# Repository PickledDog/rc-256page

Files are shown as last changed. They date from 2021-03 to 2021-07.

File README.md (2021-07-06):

# rc-256page
 128K+128K fully pageable RAM/ROM card for RC2014
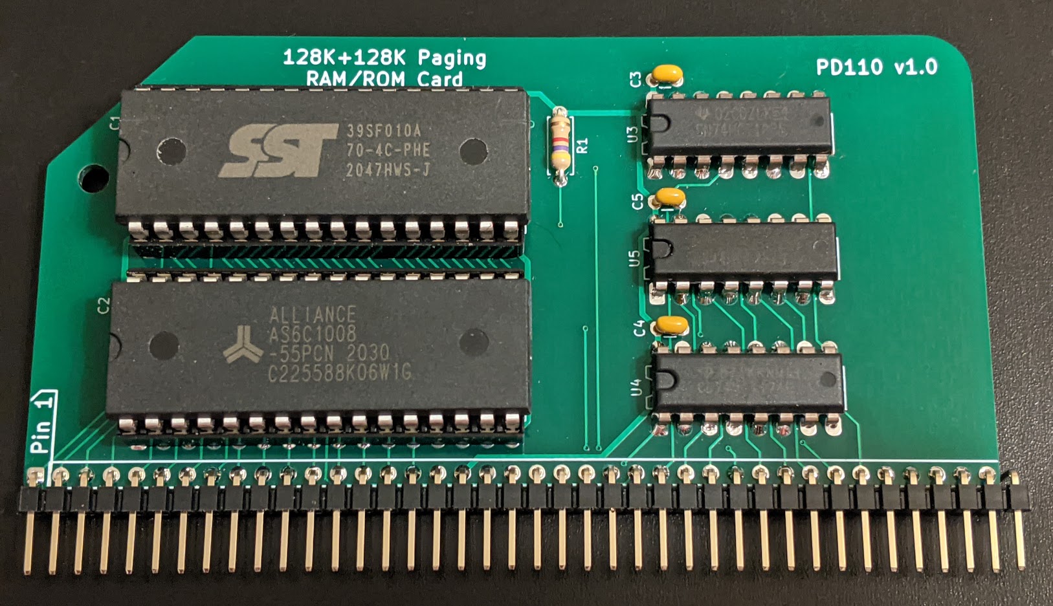
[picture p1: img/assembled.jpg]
Assembled PD110


## Overview
This RC2014-compatible board provides RAM and flash ROM, software-pageable in 32k pages. 4 ROM and 4 RAM pages may be paged into both the lower and upper 32k of Z80 memory.

## Memory details
For ROM, a SST39SF010 128k x 8 flash chip is used. It can be programmed in-place using Will Sowerbutts' FLASH4 utility (included with RomWBW). For RAM, an AS6C1008 128k x 8 SRAM is used, providing 128K of addressable memory. Both are divided into 32k pages, and are presented to the system via 2 32k address blocks (so 2 pages selectable from 8 total).

## Paging
Upon reset, ROM page 0 is mapped to both the lower **and** upper 32k (initialization code in page 0 *must* select a RAM page for normal operation). A single config register is used to set **both** currently mapped pages, presented as an I/O device at 0x78 (the address used by most "large" Z80 memory systems). The low nibble of this configures the lower page, and the high nibble the higher page. For each nibble, the high bit selects the chip (0 for ROM, 1 for RAM).

## Firmware
This board can be used as an affordable way to add [RomWBW](https://github.com/wwarthen/RomWBW) support to an RC2014 (see below). It is also presented as a programming challenge for adventurous RC2014 builders, who want an inexpensive way to add fully software-pageable memory to their computers. Beyond RomWBW, *there are currently no standard ROM images for this board* (that is, no BASIC ROM etc). None of the standard RC2014 ROM images can be used as-is. Building a ROM image (or modifying an existing one) is left up to the user.

### RomWBW
For RomWBW, a new memory mapper needs to be added. A patch file to do this can be found in the [firmware](/firmware) directory (along with an example image).

## Part selection
Bill Of Materials and part references are below. I recommend using gold-plated header for the bus connection - I use these ones from [Pololu](https://www.pololu.com/product/967) or [Sparkfun](https://www.sparkfun.com/products/553). A nice detail of these, is that they sit at the same height as double-row header in a backplane.

The specified parts are just the ones I used, and can be substituted as needed - Mouser links provided for convenience and reference.

| Reference | Value | Qty | Mouser link |
| --- | ----- | --- | --- |
| C1-C5 | 100nF ceramic | 5 | [KEMET C315C104M5U5TA](https://www.mouser.com/ProductDetail/C315C104M5U5TA7303) |
| J1 | 1x40 right-angle header | 1 | [Wurth 61304011021](https://www.mouser.com/ProductDetail/61304011021) |
| R1 | 4k7Ω resistor | 1 | [Yageo CFR-25JT-52-4K7](https://www.mouser.com/ProductDetail/CFR-25JT-52-4K7) |
| U1 | SST39SF010 NOR flash | 1 | [Microchip SST39SF010A-70-4C-PHE](https://www.mouser.com/ProductDetail/SST39SF010A-70-4C-PHE) |
| U2 | AS6C1008 SRAM | 1 | [Alliance AS6C1008-55PCN](https://www.mouser.com/ProductDetail/AS6C1008-55PCN) |
| | sockets | 2 | [Amphenol DILB32P-223TLF](https://www.mouser.com/ProductDetail/DILB32P-223TLF) |
| U3 | 74HCT138 | 1 | [TI SN74HCT138N](https://www.mouser.com/ProductDetail/SN74HCT138N) |
| U4 | 74HCT174 | 1 | [TI CD74HCT174E](https://www.mouser.com/ProductDetail/CD74HCT174E) |
| U5 | 74HCT257 | 1 | [TI SN74HCT257N](https://www.mouser.com/ProductDetail/SN74HCT257N) |

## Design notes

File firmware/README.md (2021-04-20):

# Firmware
This directory contains firmware source and binaries for the board. As of now, it only contains changes to RomWBW.

## RomWBW changes
These changes apply to RomWBW 3.1.1 (the current `dev` branch at time of writing). They were compared against RomWBW 3.1.1-pre.71 on 2021/04/19. The **.diff** files apply to files in `Source/HBIOS`, and the config **.asm** should be placed in `Source/HBIOS/Config`. A prebuilt ROM image is provided. To build this image under Windows, run `BuildShared`, then `BuildROM RCZ80 pd256 128` (both from `Source`).

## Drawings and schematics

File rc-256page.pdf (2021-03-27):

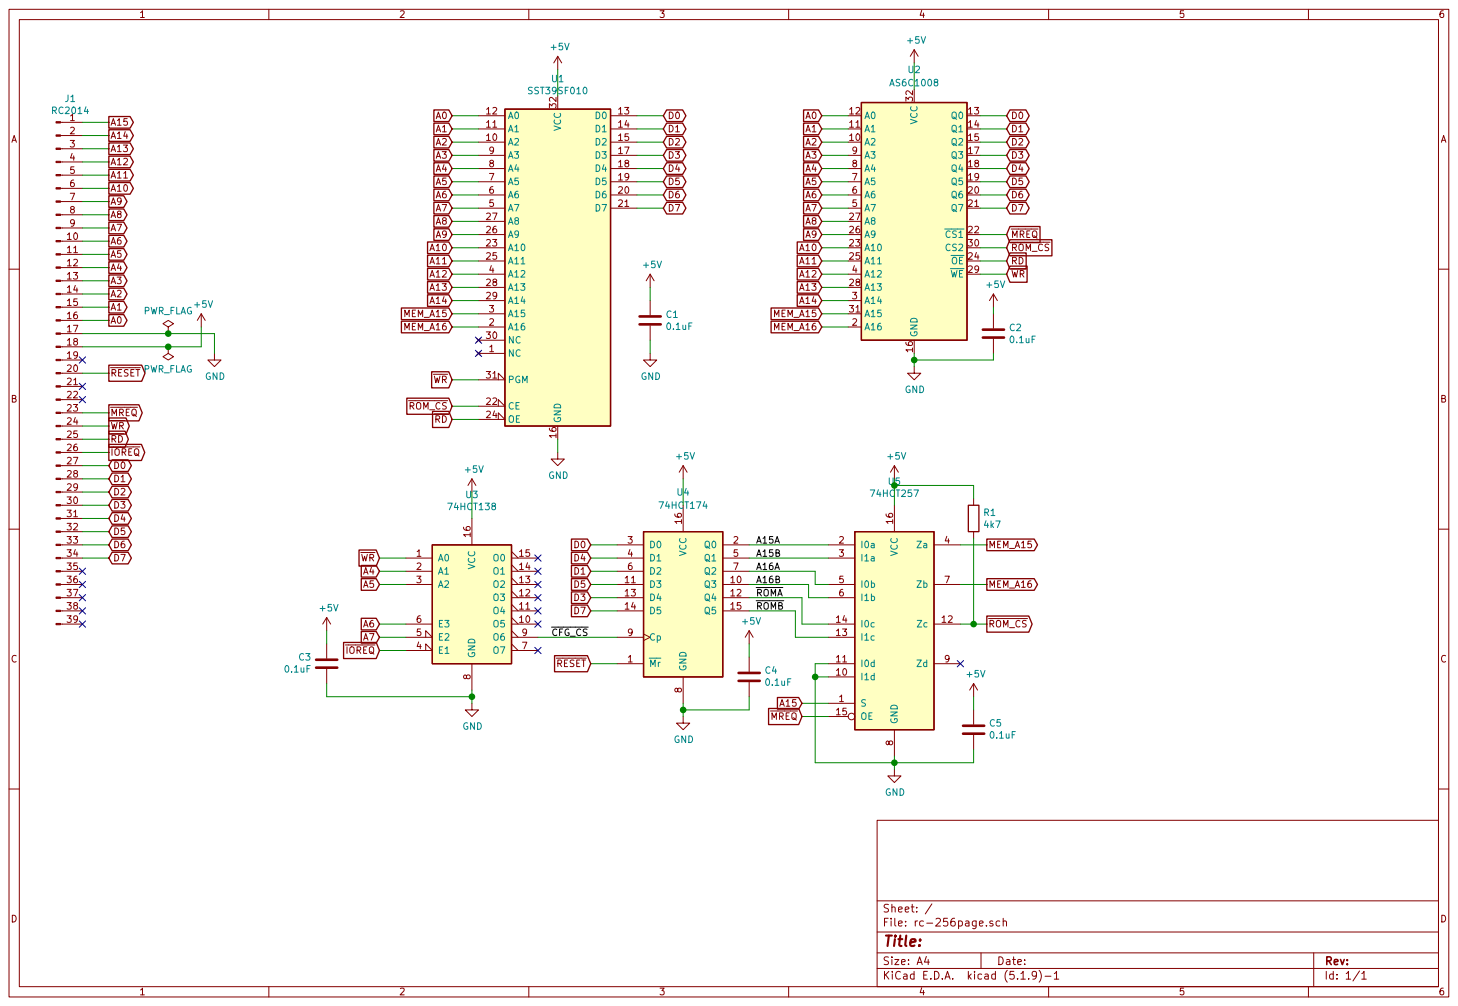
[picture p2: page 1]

File: rc-256page.sch Sheet: / S 1

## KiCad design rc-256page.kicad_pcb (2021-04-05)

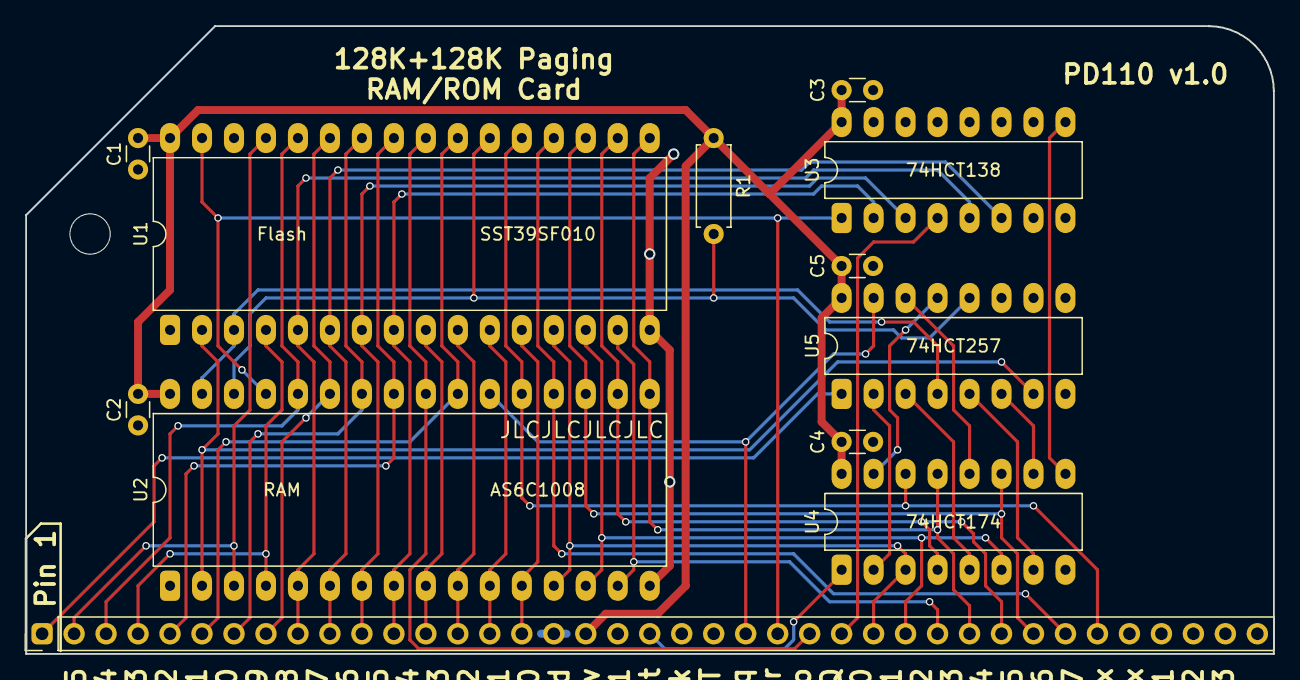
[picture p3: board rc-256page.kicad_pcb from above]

Board: 2 copper layers, 99.1 x 49.9 mm, 12 parts (0 on the bottom side), 41 nets.

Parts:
C1, C2, C3, C4, C5: 0.1uF; C_Disc_D3.0mm_W1.6mm_P2.50mm
J1: RC2014; PinHeader_1x39_P2.54mm_Vertical
R1: 4k7; R_Axial_DIN0207_L6.3mm_D2.5mm_P7.62mm_Horizontal
U1: SST39SF010; DIP-32_W15.24mm_LongPads
U2: AS6C1008; DIP-32_W15.24mm_LongPads
U3: 74HCT138; DIP-16_W7.62mm_LongPads
U4: 74HCT174; DIP-16_W7.62mm_LongPads
U5: 74HCT257; DIP-16_W7.62mm_LongPads

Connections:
+5V: C1.1, C2.1, C3.2, C4.2, C5.2, J1.18, R1.1, U1.32, U2.32, U3.16, U4.16, U5.16
/A15A: U4.2, U5.2
/A15B: U4.5, U5.3
/A16A: U4.7, U5.5
/A16B: U4.10, U5.6
/~CFG_CS: U3.9, U4.9
/~ROMA: U4.12, U5.14
/~ROMB: U4.15, U5.13
A0: J1.16, U1.12, U2.12
A1: J1.15, U1.11, U2.11
A2: J1.14, U1.10, U2.10
A3: J1.13, U1.9, U2.9
A4: J1.12, U1.8, U2.8, U3.2
A5: J1.11, U1.7, U2.7, U3.3
A6: J1.10, U1.6, U2.6, U3.6
A7: J1.9, U1.5, U2.5, U3.5
A8: J1.8, U1.27, U2.27
A9: J1.7, U1.26, U2.26
A10: J1.6, U1.23, U2.23
A11: J1.5, U1.25, U2.25
A12: J1.4, U1.4, U2.4
A13: J1.3, U1.28, U2.28
A14: J1.2, U1.29, U2.3
A15: J1.1, U5.1
D0: J1.27, U1.13, U2.13, U4.3
D1: J1.28, U1.14, U2.14, U4.6
D2: J1.29, U1.15, U2.15
D3: J1.30, U1.17, U2.17, U4.13
D4: J1.31, U1.18, U2.18, U4.4
D5: J1.32, U1.19, U2.19, U4.11
D6: J1.33, U1.20, U2.20
D7: J1.34, U1.21, U2.21, U4.14
GND: C1.2, C2.2, C3.1, C4.1, C5.1, J1.17, U1.16, U2.16, U3.8, U4.8, U5.8, U5.10, U5.11
MEM_A15: U1.3, U2.31, U5.4
MEM_A16: U1.2, U2.2, U5.7
~IOREQ: J1.26, U3.4
~MREQ: J1.23, U2.22, U5.15
~RD: J1.25, U1.24, U2.24
~RESET: J1.20, U4.1
~ROM_CS: R1.2, U1.22, U2.30, U5.12
~WR: J1.24, U1.31, U2.29, U3.1

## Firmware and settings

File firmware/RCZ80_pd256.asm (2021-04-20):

;
;==================================================================================================
;   RC2014 Z80 PD256 CONFIGURATION
;==================================================================================================
;
; THE COMPLETE SET OF DEFAULT CONFIGURATION SETTINGS FOR THIS PLATFORM ARE FOUND IN THE
; CFG_<PLT>.ASM INCLUDED FILE WHICH IS FOUND IN THE PARENT DIRECTORY.  THIS FILE CONTAINS
; COMMON CONFIGURATION SETTINGS THAT OVERRIDE THE DEFAULTS.  IT IS INTENDED THAT YOU MAKE
; YOUR CUSTOMIZATIONS IN THIS FILE AND JUST INHERIT ALL OTHER SETTINGS FROM THE DEFAULTS.
; EVEN BETTER, YOU CAN MAKE A COPY OF THIS FILE WITH A NAME LIKE <PLT>_XXX.ASM AND SPECIFY
; YOUR FILE IN THE BUILD PROCESS.
;
; THE SETTINGS BELOW ARE THE SETTINGS THAT ARE MOST COMMONLY MODIFIED FOR THIS PLATFORM.
; MANY OF THEM ARE EQUAL TO THE SETTINGS IN THE INCLUDED FILE, SO THEY DON'T REALLY DO
; ANYTHING AS IS.  THEY ARE LISTED HERE TO MAKE IT EASY FOR YOU TO ADJUST THE MOST COMMON
; SETTINGS.
;
; N.B., SINCE THE SETTINGS BELOW ARE REDEFINING VALUES ALREADY SET IN THE INCLUDED FILE,
; TASM INSISTS THAT YOU USE THE .SET OPERATOR AND NOT THE .EQU OPERATOR BELOW. ATTEMPTING
; TO REDEFINE A VALUE WITH .EQU BELOW WILL CAUSE TASM ERRORS!
;
; PLEASE REFER TO THE CUSTOM BUILD INSTRUCTIONS (README.TXT) IN THE SOURCE DIRECTORY (TWO
; DIRECTORIES ABOVE THIS ONE).
;
#DEFINE	BOOT_DEFAULT	"H"		; DEFAULT BOOT LOADER CMD ON <CR> OR AUTO BOOT
;
#include "cfg_rcz80.asm"
;
CRTACT		.SET	FALSE		; ACTIVATE CRT (VDU,CVDU,PROPIO,ETC) AT STARTUP
;
CPUOSC		.SET	7372800		; CPU OSC FREQ IN MHZ
;
RAMSIZE		.SET	128		; SIZE OF RAM IN KB (MUST MATCH YOUR HARDWARE!!!)
MEMMGR		.SET	MM_PD		; MEMORY MANAGER: MM_[SBC|Z2|N8|Z180]
MPGSEL		.EQU	$78		; PD MEM MGR RAM PAGE SELECT REG (WRITE ONLY)
;
UARTENABLE	.SET	TRUE		; UART: ENABLE 8250/16550-LIKE SERIAL DRIVER (UART.ASM)
ACIAENABLE	.SET	TRUE		; ACIA: ENABLE MOTOROLA 6850 ACIA DRIVER (ACIA.ASM)
SIOENABLE	.SET	TRUE		; SIO: ENABLE ZILOG SIO SERIAL DRIVER (SIO.ASM)
;
TMSENABLE	.SET	FALSE		; TMS: ENABLE TMS9918 VIDEO/KBD DRIVER (TMS.ASM)
TMSTIMENABLE	.SET	FALSE		; TMS: ENABLE TIMER INTERRUPTS (REQUIRES IM1)
;
MDENABLE	.SET	FALSE		; MD: ENABLE MEMORY (ROM/RAM) DISK DRIVER (MD.ASM)
;
FDENABLE	.SET	FALSE		; FD: ENABLE FLOPPY DISK DRIVER (FD.ASM)
FDMODE		.SET	FDMODE_RCWDC	; FD: DRIVER MODE: FDMODE_[DIO|ZETA|ZETA2|DIDE|N8|DIO3|RCSMC|RCWDC|DYNO|EPWDC]
;
IDEENABLE	.SET	TRUE		; IDE: ENABLE IDE DISK DRIVER (IDE.ASM)
;
PPIDEENABLE	.SET	TRUE		; PPIDE: ENABLE PARALLEL PORT IDE DISK DRIVER (PPIDE.ASM)
;
PRPENABLE	.SET	FALSE		; PRP: ENABLE ECB PROPELLER IO BOARD DRIVER (PRP.ASM)

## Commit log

2021-03-27 Initial commit of rc-256page/PD110
    [rc-256page-B_Cu.gbr, rc-256page-B_Mask.gbr, rc-256page-B_SilkS.gbr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]
2021-04-05 Minor layout tweaks
    [rc-256page-B_Cu.gbr, rc-256page-B_Mask.gbr, rc-256page-B_SilkS.gbr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]
2021-07-06 Fix missing BOM entry
